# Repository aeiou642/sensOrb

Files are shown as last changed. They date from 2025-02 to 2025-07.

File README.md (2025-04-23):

PlatformIO Notes:
- Install PIO via. VSCode and follow standard installation instructions
- In the platformio.ini file, change the following;
- upload_port to whatever port the Serial to UART for the UPDI is connected to
- monitor_port to whatever port the Serial to UART the actual serial monitor is connected to

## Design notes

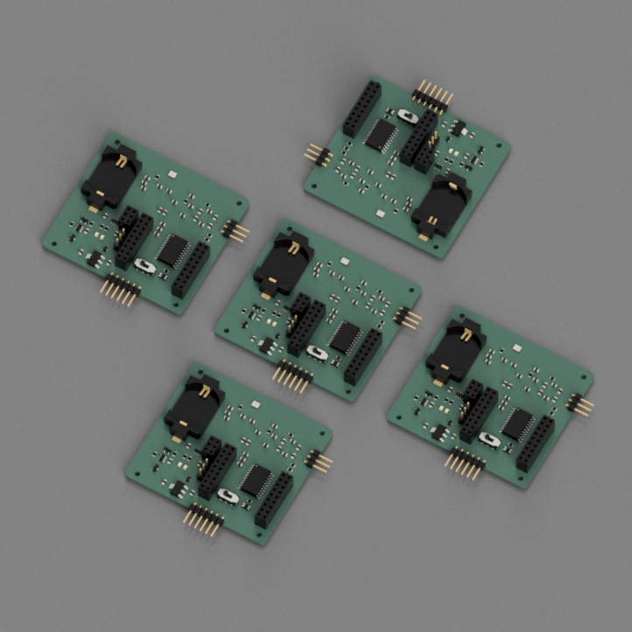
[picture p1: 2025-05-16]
Schematics & PCB/sensOrb/Node Layout v2.png

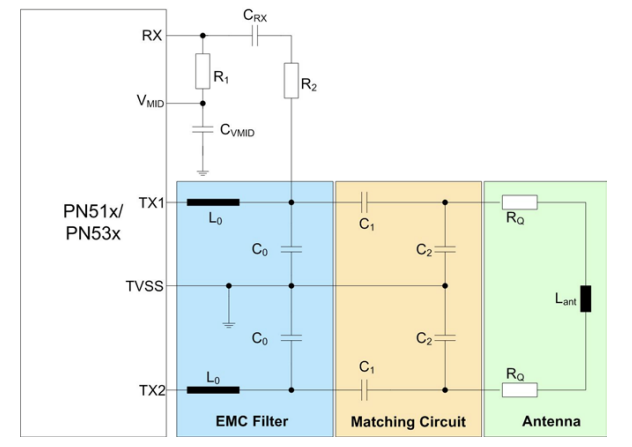
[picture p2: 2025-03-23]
Documentation/PN532/Antenna_RF_Design/AT1_Diagram.png

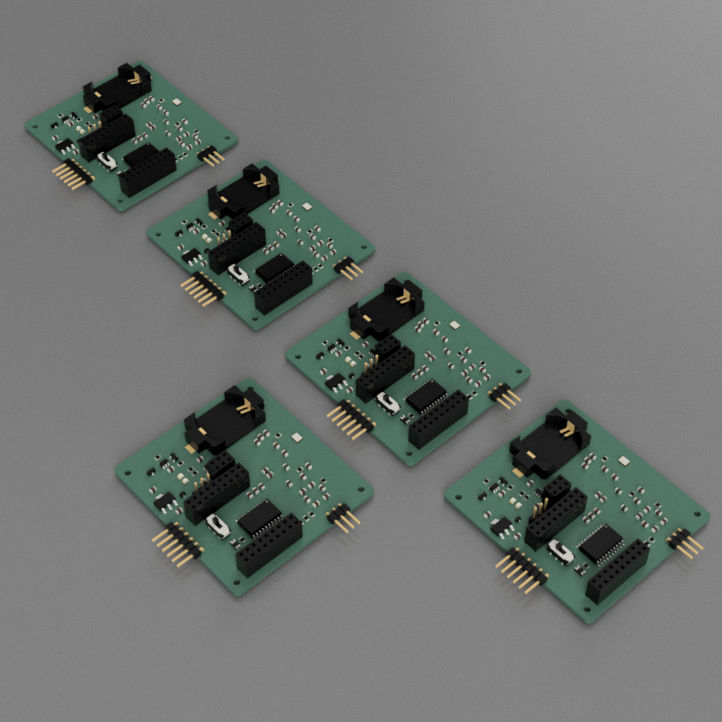
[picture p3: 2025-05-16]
Schematics & PCB/sensOrb/Node Layout v3.png

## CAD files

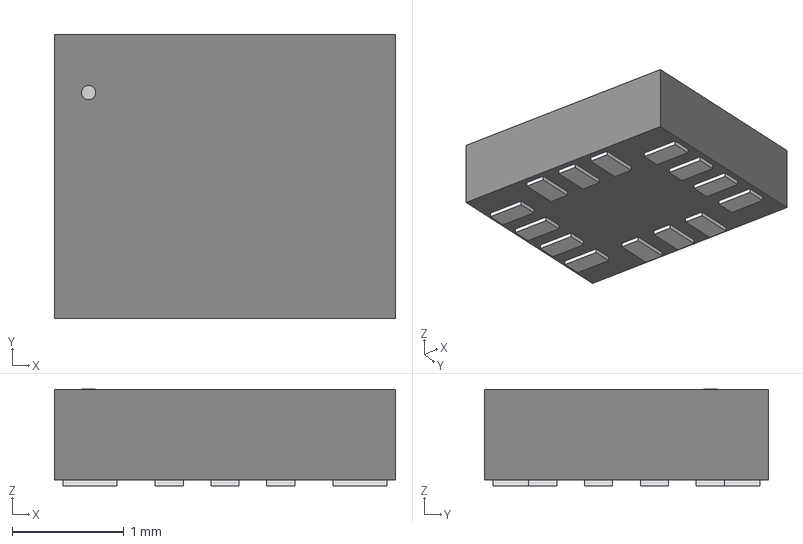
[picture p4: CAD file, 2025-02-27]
Documentation/BNO08x/BMI270_BOS.step
3.05 x 2.54 x 0.866 mm

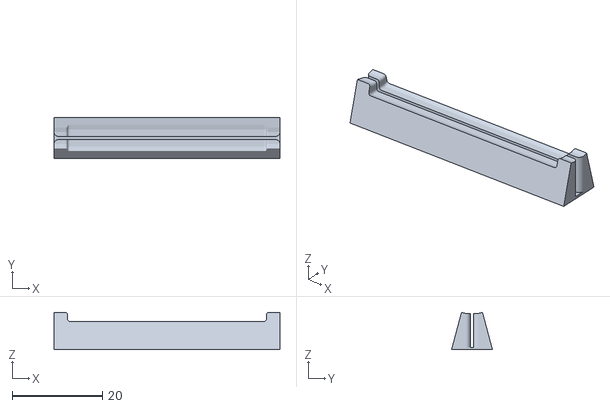
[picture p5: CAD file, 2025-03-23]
Documentation/PN532/PN532_Mount.stl
50.0 x 9.07 x 8.26

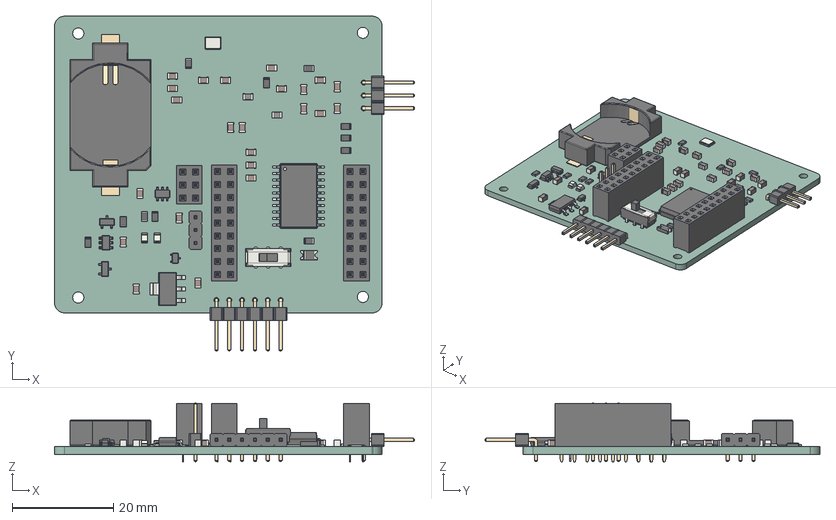
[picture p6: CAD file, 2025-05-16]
Schematics & PCB/sensOrb/salp_board.step
71.2 x 66.2 x 11.6 mm
R_0805_2012Metric x 11
SOT_223
L_0805_2012Metric x 2
C_0805_2012Metric x 23
PinSocket_2x03_P2.54mm_Vertical
PinHeader_1x06_P254mm_Horizontal
CuK_JS202011CQN_DPDT_straight
PinSocket_2x09_P2.54mm_Vertical x 2
LED_0805_2012Metric x 2
SOT_23_6
SOT_323_SC_70
PinHeader_1x03_P254mm_Horizontal
PinHeader_1x03_P254mm_Vertical
Keystone_1060_1x2032
SOT_23 x 2
TSOT_23_6
SOIC_20W_75x128mm_P127mm
D_1206
Crystal_SMD_SeikoEpson_TSX3225-4Pin_3.2x2.5mm_HandSoldering
_autosave-salp_board_PCB

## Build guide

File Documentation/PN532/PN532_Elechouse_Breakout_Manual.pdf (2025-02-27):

www.elechouse.com

# PN532 NFC RFID Module User Guide

Version V4

Introduction

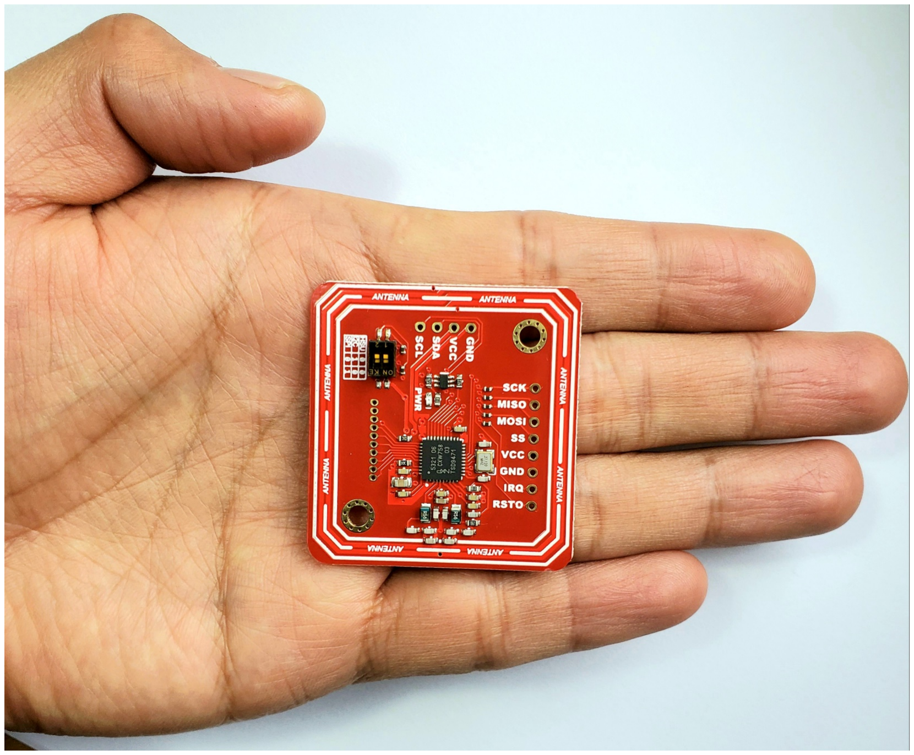
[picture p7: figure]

Near field communication (http://www.nfc-forum.org/aboutnfc) ( (http://www.nfc-forum.org/aboutnfc)NFC) (http://www.nfc-forum.org/aboutnfc) is (http://www.nfc-forum.org/aboutnfc) a set of standards for smartphones and similar devices to establish radio communication with each other by touching them together or bringing them into close proximity, usually no more than a few centimeters.

For electronics geeks, we also want to use NFC technology to make our own things. So we build this NFC RFID module. This module is built around NXP PN532. NXP PN532 is very popular in NFC area. And the company offers much technology documents to help developers. We developed this module based on the official documents. To make things easier, we also build library for this module.

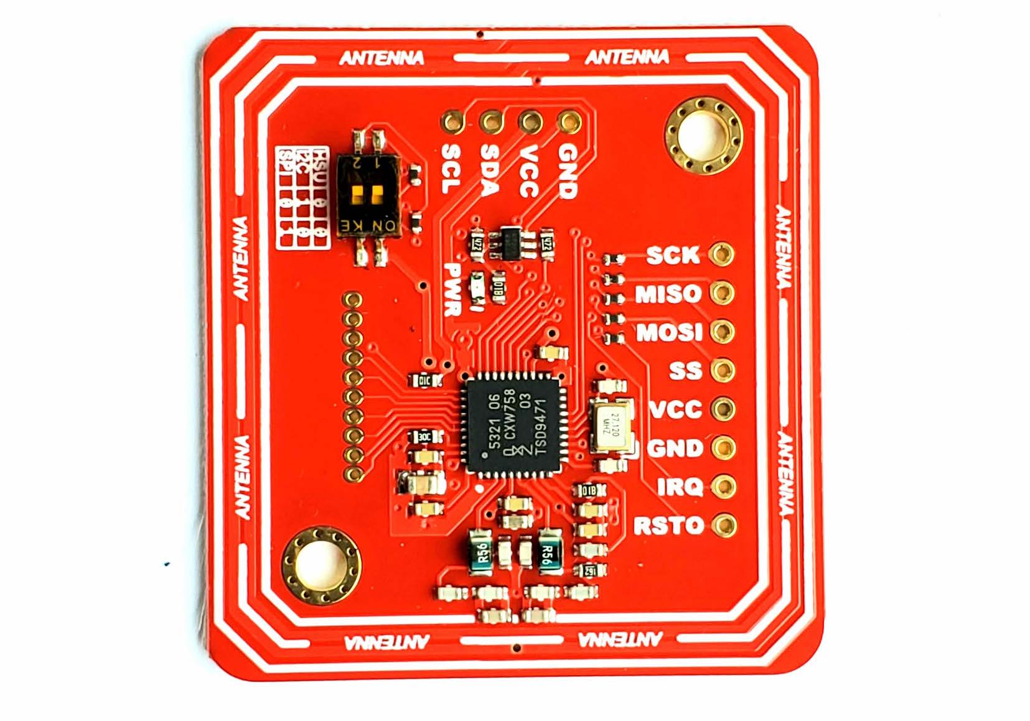
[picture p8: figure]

We have updated this module to version 4.

Compared with V3 have the following improvement:

Performance | PN532 NFC V3 | PN532 NFC V4 | Description
Reading Distance on PVC Mifare tag | 5~6cm | 6~8cm | Improved performance on IOS14443A tags
Reading Distance on PVC SRT512 | 1~2cm | 2~4cm | Improved performance on IOS14443B tags

Feature
1. Compatibility: it is compatible with V3 both in hardware and software.
2. Smaller: the size now is as small as 42.7mm*40.4mm*4mm
3. Easy to change mode: with a small SMD toggle Switch, it becomes very easy to change among IIC, SPI and HSU modes
4. Longer distance: the reading distance becomes 6~8cm

5. Open source Arduino library

Features
1. Support II2, SPI and HSU (High Speed UART)
2. RFID reader/writer mode support
- Mifare 1k, 4k, Ultralight, and DesFire cards
- ISO/IEC 14443-4 cards such as CD97BX, CD light, DesFire, P5CN072 (SMX)
- Innovision Jewel cards such as IRT5001 card
- FeliCa cards such as RCS_860 and RCS_854
3. Plug and play, Arduino compatible
4. Built in PCB Antenna, with 6cm~8cm communication distance
5. On-board level shifter, Standard 5V TTL for I2C and UART, 3.3V TTL SPI
6. Work as RFID reader/writer
7. Work as 1443-A card or a virtual card
8. Support NFC with Android phone
9. Small size: 43mm*41mm*4mm

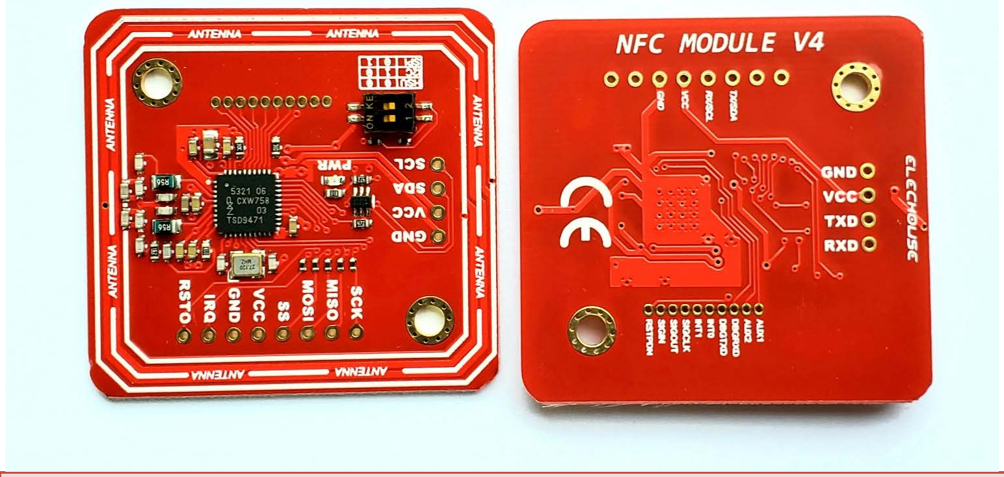
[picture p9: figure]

Interface

- VCC: 3.3V~5V
- Currency: Max 120mA

- I2C/UART: 3.3V~24V TTL
- SPI: 3.3V TTL with 100 ohm resistors in series. It could be connected directly to 5V interface of microcontroller such as Arduino.

The I2C and HSU shares the same pins. The definition of IIC pins is printed at front and the HSU’s is printed at the back. The HSU mode is configured as the default mode. But you could change the interface by setting the toggle switch.

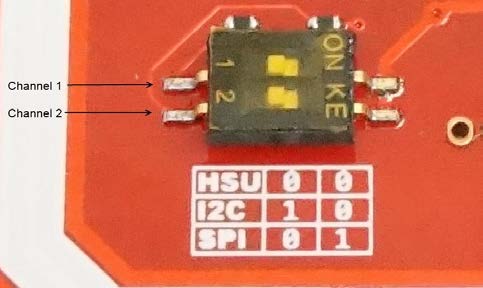
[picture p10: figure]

The switch setting is shown as follows: Working Interface Channel 1 Channel 2
HSU | OFF | OFF
I2C | ON | OFF
SPI | OFF | ON

We break all the PN532 pins out. The 1.27mm connector hole contains those pins which might not be used for most users. If some developers need to connect those pins, we could supply connectors.

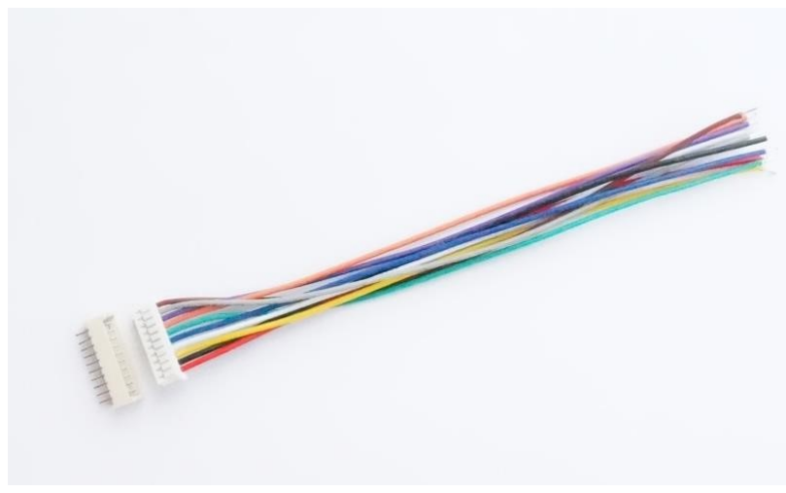
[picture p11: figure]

You could find this product here. (http://www.elechouse.com/elechouse/index.php?main_page=product_info&cPath=105_298&products_id=2244)

Hardware Installation

Solder the connector
The bended male pins come with the NFC board.

Some users might need soldering other types of connectors or directly solder wires on it. Anyway, make sure the wires go across the antenna lines in 90 degree.

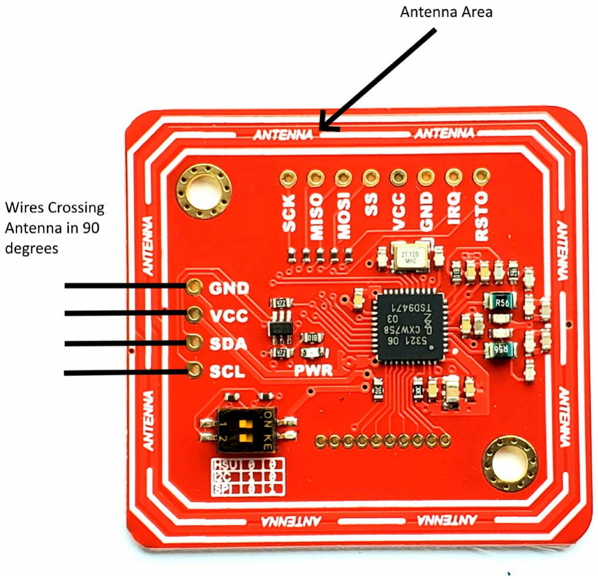
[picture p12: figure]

Connect with Arduino
If without the sensor shield, please connect as following:
Mode | PN532 Module | Arduino UNO | Arduino Leonardo | Arduino Mega (2560) | Arduino Due
Power | VCC | 5V | 5V | 5V | 5V
| GND | GND | GND | GND | GND
IIC/I2C Mode | SDA | A4/SDA | Pin 2 /SDA | Pin 20 /SDA | Pin 20 /SDA
| SCL | A5/SCL | Pin 3/SCL | Pin 21/SCL | Pin 21/SCL
HSU Mode | TXD | Pin 0 | Could not
present
message in
Serial
Monitor on
PC
| | | Pin 0 | Pin 19 | Pin 19
| RXD | Pin 1 | Pin 1 | Pin 18 | Pin 18
SPI Mode | SCK | Pin 13 or ICSP-3 | ICSP-3 | Pin 52 or ICSP-3 | ICSP-3 | Note: SPI on Due is still in developing
MISO | Pin 12 or ICSP-1 | ICSP-1 | Pin 50 or ICSP-1 | ICSP-1
MOSI | Pin 11 or ICSP-4 | ICSP-4 | Pin 51 or ICSP-4 | ICSP-4
SS | Pin 10 | Pin 10 | Pin 10 | Pin 10
Arduino UNO only has one serial interface which is also connected to USB port to PC. In HSU mode, the serial monitor could not be used as message displaying windows.

Function Test

RFID Reader/Writer
Here we show how to read and write RFID card with this module.

Download the library (https://github.com/elechouse/PN532) PN532 (https://github.com/elechouse/PN532) at (https://github.com/elechouse/PN532) our github page. You could find 4 folders in the library. Unzip the 4 folders at the library folder in Arduino IDE.

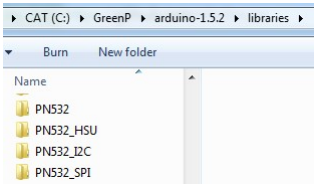
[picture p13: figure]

Start Arduino IDE and choose the example:

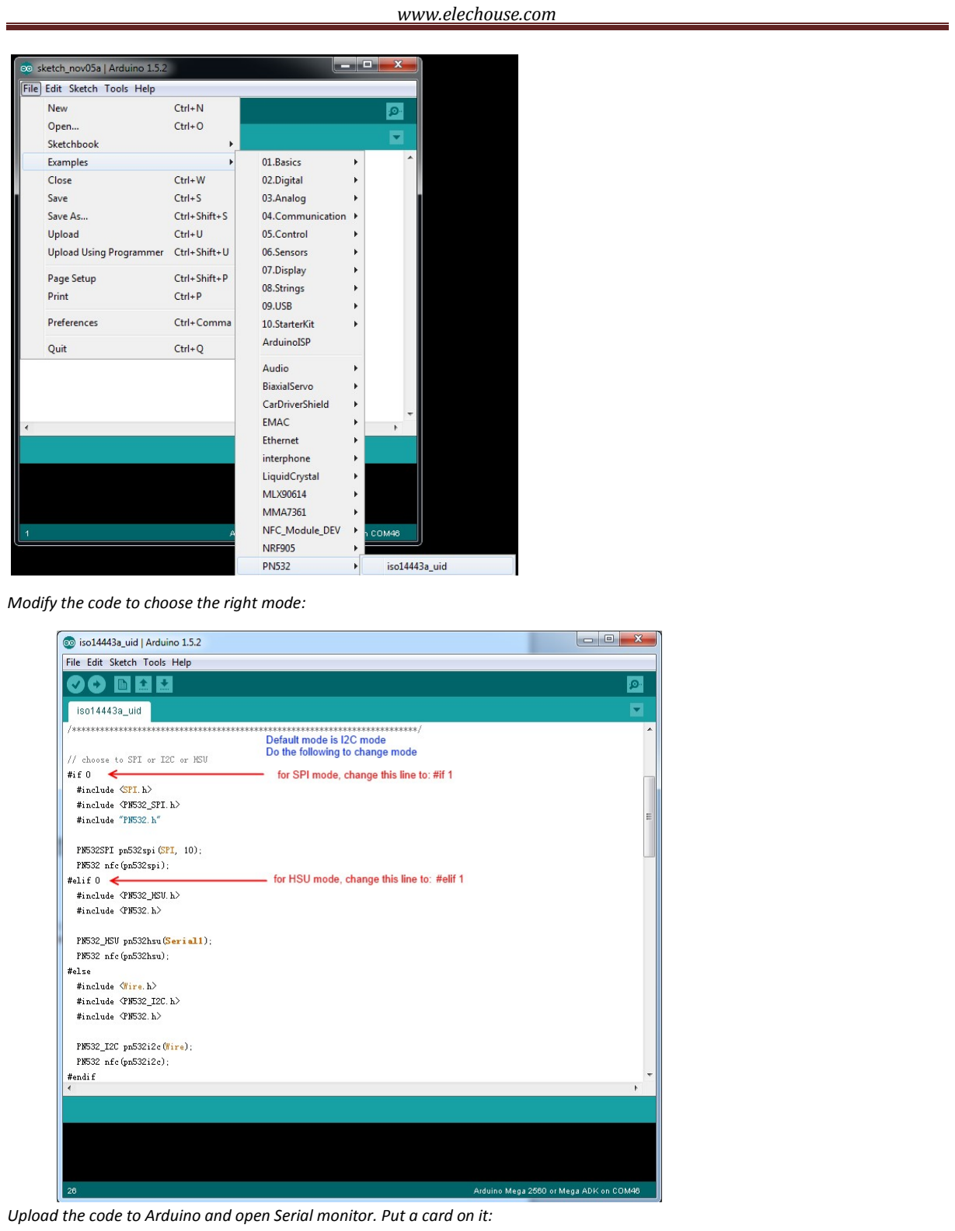
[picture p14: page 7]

Modify the code to choose the right mode:

Upload the code to Arduino and open Serial monitor. Put a card on it:

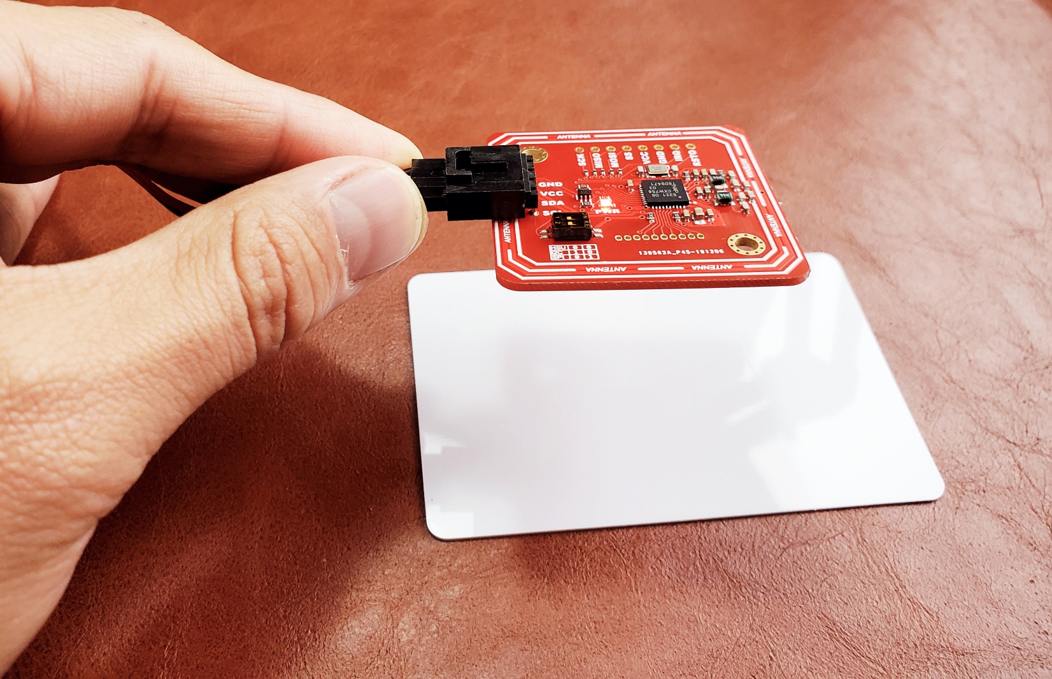
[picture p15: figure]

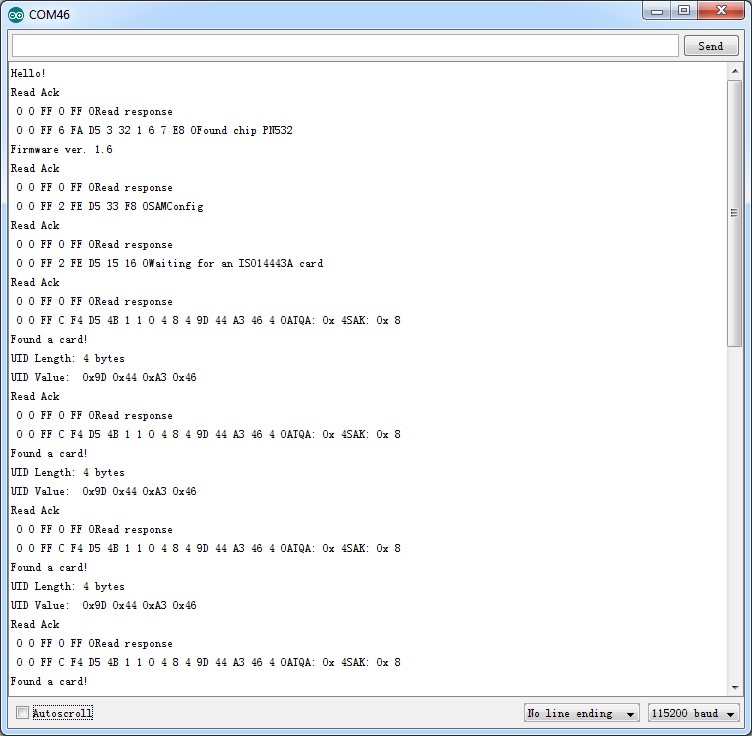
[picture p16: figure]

You could also try other reading/writing example code in the library.

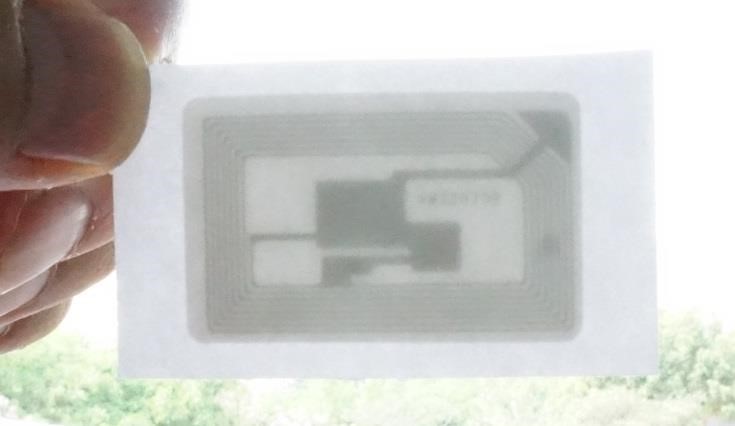
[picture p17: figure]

It also supports reading flexible tag. We tested flexible tags of Mifare 1 S50 and Ultralight. The reading distance is up to 5cm.

You could find those flexible tags here. (http://www.elechouse.com/elechouse/index.php?main_page=product_info&cPath=90_93&products_id=2243)

P2P NFC
Currently we are still developing the software. The P2P NFC communication between two PN532 modules is only supported by I2C mode. Please download this library. (http://www.elechouse.com/elechouse/images/product/PN532%20NFC%20Module/PN532_NFC_elechouse.rar)
Note, while testing this library, please remove the libraries in the testing above (or other PN532 libraries) to other folders. Otherwise they might conflict.

Here we need two Arduino boards to test this function. Basically we will program one NFC module as Initiator, and the other as Target.

Please upload the following two examples to the two Arduino board:

- NFC_p2p_initiator
- NFC_p2p_target

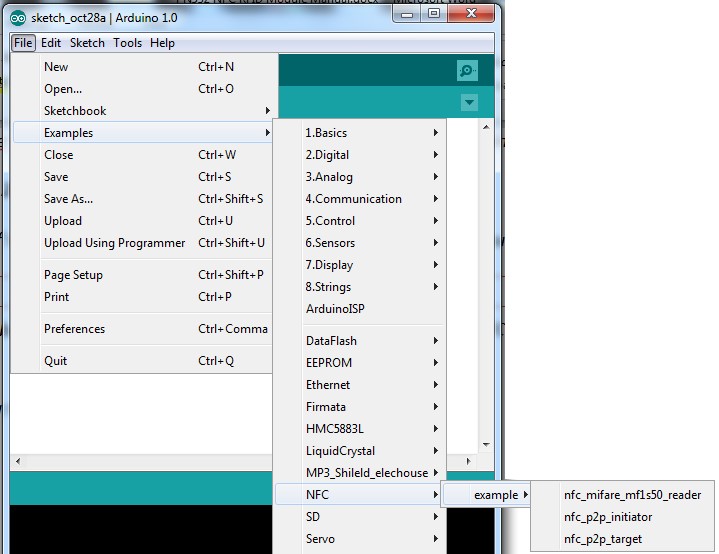
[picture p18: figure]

After uploading the sketches, open the Serial Monitor. Please note that Arduino IDE doesn’t support opening 2 Serial Monitors. So you need another Serial Tool. Here we have 2 versions of Arduino IDE installed in my PC: Arduino 0022 and Arduino 1.0. We open the two and could have two Serial Monitor working. Note the baud rate is 115200.

Target:

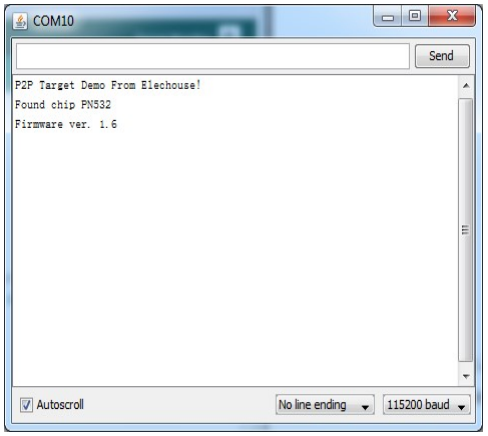
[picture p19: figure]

Initiator:

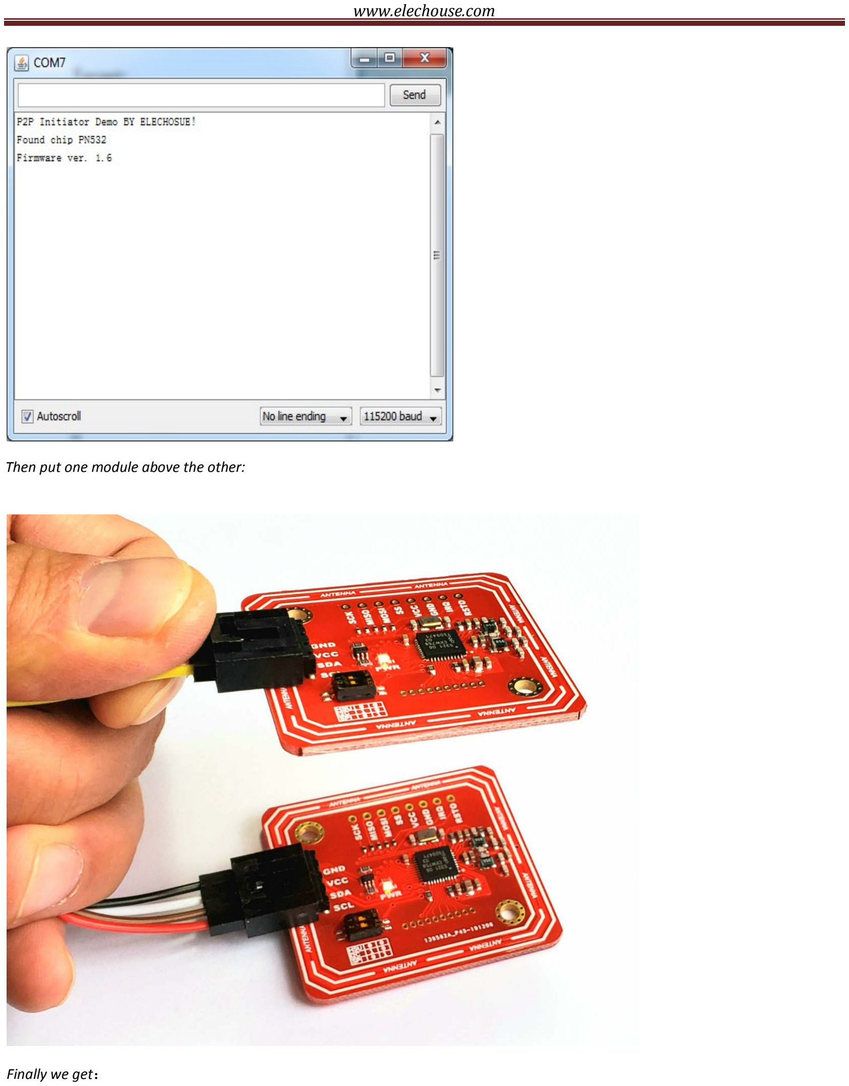
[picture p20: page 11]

Then put one module above the other:

Finally we get：

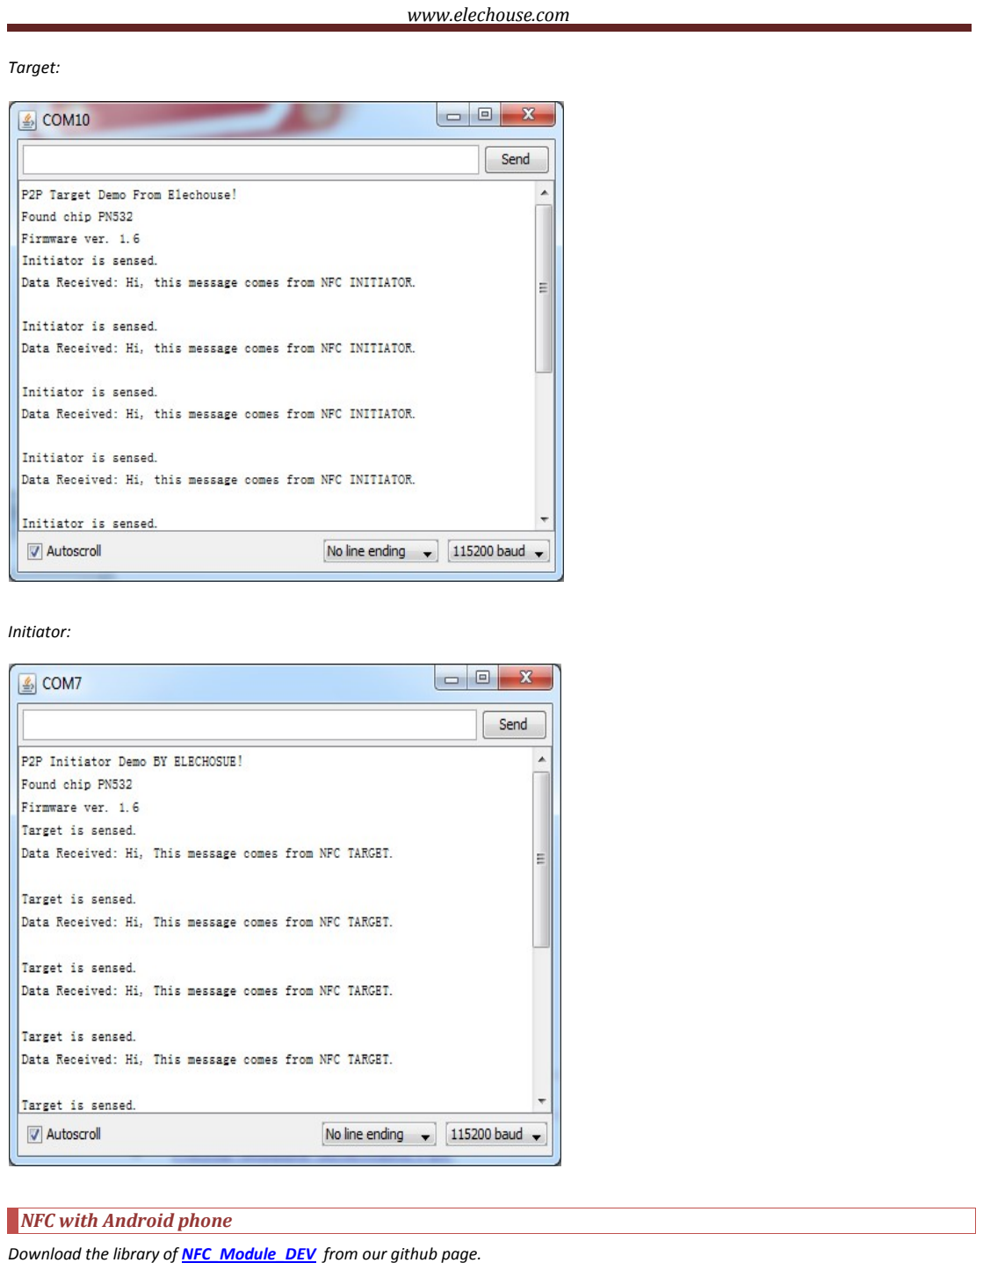
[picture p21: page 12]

Target:

Initiator:

NFC with Android phone
Download the library of (https://github.com/elechouse/NFC_Module_DEV) NFC_Module_DEV (https://github.com/elechouse/NFC_Module_DEV) from our github page.

Note, while testing this library, please remove the libraries in the testing above (or other PN532 libraries) to other folders. Otherwise they might conflict.

Currently this library only supports HSU mode. We are still working on more modes. If you want to use SPI mode, you could try (https://github.com/Seeed-Shield/NFC_Shield_DEV) NFC_Shield_DEV. (https://github.com/Seeed-Shield/NFC_Shield_DEV) Just connect Arduino with our PN532 module through SPI interface in the way shown in the table above.

Open the example in Arduino Due:

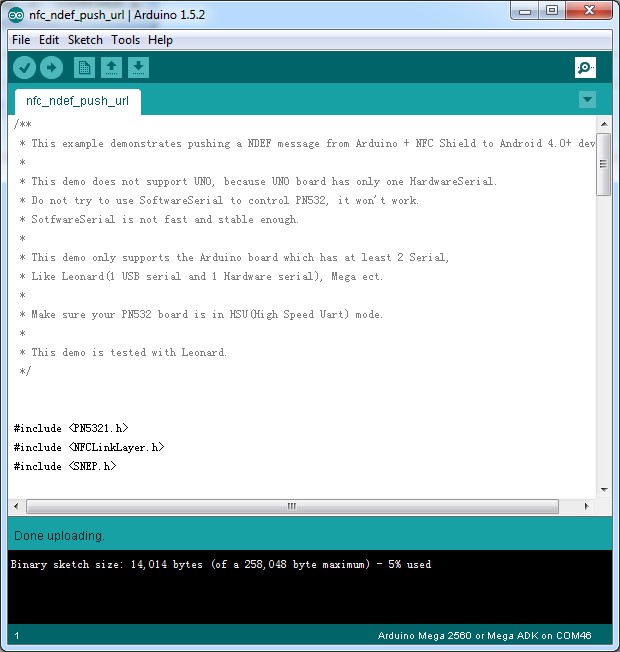
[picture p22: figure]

Upload the code to Arduino, and open Serial Monitor:

Put an NFC-support phone on the module:

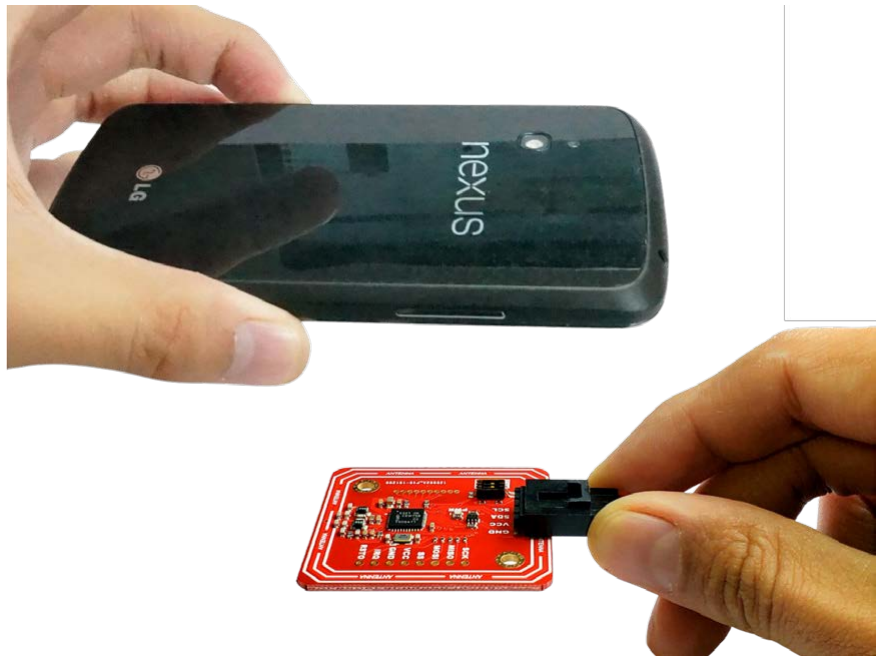
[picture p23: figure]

On Android phone, if you have set the default browser, it will start the browser and visit our website: www.elechouse.com

If it doesn’t start the browser, please open the browser and try again. Here we tested HTC one and Google Nexus 4. They all work very well. Different NFC phones might have different NFC ICs. If your phone doesn’t work with it, try to google information to check if your phone NFC chip is compatible with PN532.

On Serial Monitor you could get the following result:

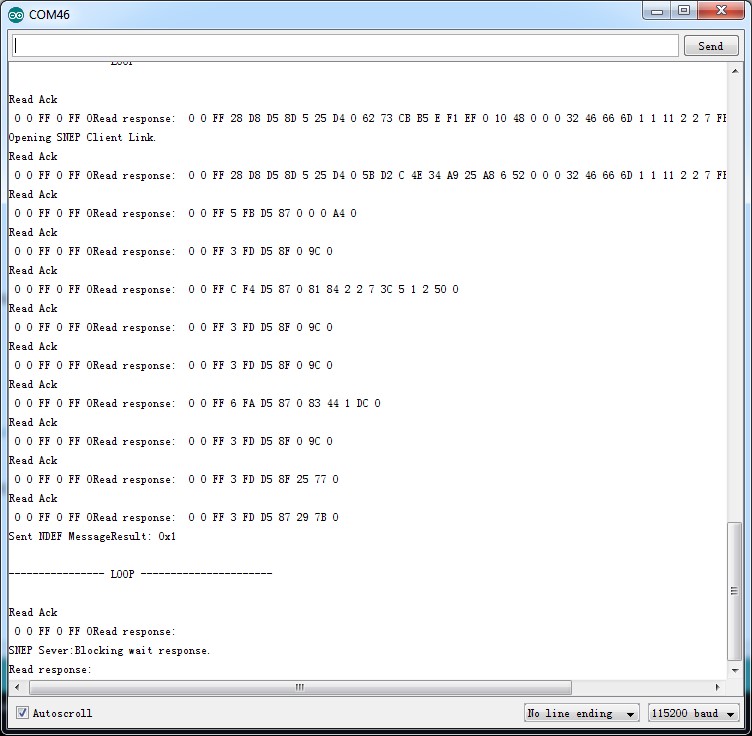
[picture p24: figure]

Useful link
PN532 Module Schematic PDF (http://www.elechouse.com/elechouse/images/product/PN532_module_V3/PN532_shematic_drowing.pdf)
NXP PN532 User Manual (http://www.nxp.com/documents/user_manual/141520.pdf)
DWG DIMENSION FILE (http://www.elechouse.com/elechouse/images/product/NFCV4/NFC_V4_dimension.DWG)
Library: (https://github.com/elechouse/PN532) PN532 (https://github.com/elechouse/PN532) or (https://github.com/elechouse/NFC_Module_DEV) NFC_Module_DEV (https://github.com/elechouse/NFC_Module_DEV)

Where to buy
Please visit this page to buy this product: (http://www.elechouse.com/elechouse/index.php?main_page=product_info&cPath=90_93&products_id=2242) PN532 NFC module (http://www.elechouse.com/elechouse/index.php?main_page=product_info&cPath=90_93&products_id=2242)

Disclaimer and Revisions
[FCC Declare]

The information in this document may change without notice. If you have any problem about it, please visit www.elechouse.com to contact us.

Revision History
Rev. | Date | Author | Description

A | Oct. 25th , 2012 | Wilson | Initial version
B | Nov. 5th, 2013 | Wilson | Modify information for V3

FCC WARNING
FCC Caution: Any changes or modifications not expressly
approved by the party responsible for compliance could void the user's authority to operate this equipment.
This device complies with Part 15 of the FCC Rules.
Operation is subject to the following two conditions: (1) This device may not cause harmful interference, and (2) this device must accept any interference received, including interference that may cause undesired operation.
This device and its antenna(s) must not be co-located or operating in conjunction with any other antenna or transmitter.
15.105 Information to the user.
(b) For a Class B digital device or peripheral, the instructions furnished the
user shall include the following or similar statement, placed in a prominent location in the text of the manual:
Note: This equipment has been tested and found to comply
with the limits for a Class B digital device, pursuant to part 15 of the FCC Rules. These limits are designed to provide reasonable protection against harmful interference in a residential installation. This equipment generates, uses and can radiate radio frequency energy and, if not installed and used in
accordance with the instructions, may cause harmful interference to radio communications. However, there is no guarantee that interference will not occur in a particular installation. If this equipment does cause harmful interference to radio or television reception, which can be determined by turning the equipment off and on, the user is encouraged to try to correct the interference by one or more of the following measures:
—Reorient or relocate the receiving antenna.
—Increase the separation between the equipment and receiver.
—Connect the equipment into an outlet on a circuit different from that to which
the receiver is connected.
—Consult the dealer or an experienced radio/TV technician for help.
This equipment complies with FCC radiation exposure limits set forth for an uncontrolled environment. This equipment should be installed and operated with minimum distance 20 cm between the radiator and your body.
Radiation Exposure Statement:
This equipment complies with FCC radiation exposure limits set forth for an uncontrolled environment.
This transmitter must not be co-located or operating in conjunction with any other antenna or transmitter.
The availability of some specific channels and/or operational frequency bands are country dependent and are firmware programmed at the factory to match the intended destination.
The firmware setting is not accessible by the end user.
The final end product must be labelled in a visible area with the following: “Contains Transmitter Module 2ABVM-ELECHNFCV4”

## Requirement per KDB996369 D03

### 2.2 List of applicable FCC rules

List the FCC rules that are applicable to the modular transmitter. These are the rules that specifically establish the bands of operation, the power, spurious emissions, and operating fundamental frequencies. DO NOT list compliance to unintentional-radiator rules (Part 15 Subpart
B) since that is not a condition of a module grant that is extended to a host manufacturer. See also Section 2.10 below concerning the need to notify host manufacturers that further testing is required.3
Explanation: This module meets the requirements of FCC part 15C (15.225).it specifically establish the Radiated Spurious Emission, Frequency Tolerance, Occupied Bandwidth

### 2.3 Summarize the specific operational use conditions

Describe use conditions that are applicable to the modular transmitter, including for example any limits on antennas, etc. For example, if point-to-point antennas are used that require reduction in power or compensation for cable loss, then this information must be in the instructions. If the use condition limitations extend to professional users, then instructions must state that this information also extends to the host manufacturer’s instruction manual. In addition, certain information may also be needed, such as peak gain per frequency band and minimum gain, specifically for master devices in 5 GHz DFS bands.
Explanation: The EUT has an pcb antenna, the antenna can be replaced by other authorized antennas, and the gain of each replacement antenna is no more than 5dBi

### 2.4 Limited module procedures

If a modular transmitter is approved as a “limited module,” then the module manufacturer isresponsible for approving the host environment that the limited module is used with. The manufacturer of a limited module must describe, both in the filing and in the installation instructions, the alternative means that the limited module manufacturer uses to verify that the host meets the necessary requirements to satisfy the module limiting conditions.
A limited module manufacturer has the flexibility to define its alternative method to address the conditions that limit the initial approval, such as: shielding, minimum signaling amplitude, buffered modulation/data inputs, or power supply regulation. The alternative method could include that the limited module manufacturer reviews detailed test data or host designs prior to giving the host manufacturer approval.

This limited module procedure is also applicable for RF exposure evaluation when it is necessary to demonstrate compliance in a specific host. The module manufacturer must state how control of the product into which the modular transmitter will be installed will be maintained such that full compliance of the product is always ensured. For additional hosts other than the specific host originally granted with a limited

module, a Class II permissive change is required on the module grant to register the additional host as a specific host also approved with the module.
Explanation: The module is a limit module.

### 2.6 RF exposure considerations

It is essential for module grantees to clearly and explicitly state the RF exposure conditions that permit a host product manufacturer to use the module. Two types of instructions are required for RF exposure information: (1) to the host product manufacturer, to define the application conditions (mobile, portable – xx cm from a person’s body); and (2) additional text needed for the host product manufacturer to provide to end users in their end-product manuals. If RF exposure statements and use conditions are not provided, then the host product manufacturer is required to take responsibility of the module through a change in FCC ID (new application).

Explanation: This module complies with FCC RF radiation exposure limits set forth for an uncontrolled environment, This equipment should be installed and operated with a minimum distance of 20 centimeters between the radiator and your body." This module is designed to comply with the FCC statement, FCC ID is: 2ABVM-ELECHNFCV4.

### 2.7 Antennas

A list of antennas included in the application for certification must be provided in the instructions. For modular transmitters approved as limited modules, all applicable professional installer instructions must be included as part of the information to the host product manufacturer. The antenna list shall also identify the antenna types (monopole, PIFA, dipole, etc. (note that for example an “omni-directional antenna” is not considered to be a specific “antenna type”)).
For situations where the host product manufacturer is responsible for an external connector, for example with an RF pin and antenna trace design, the integration instructions shall inform the installer that unique antenna connector must be used on the Part 15 authorized transmitters used in the host product. The module manufacturers shall provide a list of acceptable unique connectors.
Explanation: The EUT has an pcb antenna, the antenna can be replaced by other authorized antennas, and the gain of each replacement antenna is no more than 5dBi

### 2.8 Label and compliance information

Grantees are responsible for the continued compliance of their modules to the FCC rules. This includes advising host product manufacturers that they need to provide a physical or e-label stating “Contains FCC ID” with their finished product. See Guidelines for Labeling and User Information for RF Devices – KDB Publication 784748.

Explanation: The host system using this module, should have label in a visible area indicated the following texts: "Contains FCC ID: 2ABVM-ELECHNFCV4.

### 2.9 Information on test modes and additional testing requirements5

Additional guidance for testing host products is given in KDB Publication 996369 D04 Module Integration Guide. Test modes should take into consideration different operational conditions for a stand-alone modular transmitter in a host, as well as for multiple simultaneously transmitting modules or other transmitters in a host product.
The grantee should provide information on how to configure test modes for host product evaluation for different operational conditions for a stand-alone modular transmitter in a host, versus with multiple, simultaneously transmitting modules or other transmitters in a host.
Grantees can increase the utility of their modular transmitters by providing special means, modes, or instructions that simulates or characterizes a connection by enabling a transmitter. This can greatly simplify a host manufacturer’s determination that a module as installed in a host complies with FCC requirements.
Explanation: HK ELECHOUSE ELECTRONICS TECHNOLOGY CO.,LIMITED can increase the utility of our modular transmitters by providing instructions that simulates or characterizes a connection by enabling a transmitter.

### 2.10 Additional testing, Part 15 Subpart B disclaimer

The grantee should include a statement that the modular transmitter is only FCC authorized for the specific rule parts (i.e., FCC transmitter rules) listed on the grant, and that the host product manufacturer is responsible for compliance to any other FCC rules that apply to the host not covered by the modular transmitter grant of certification. If the grantee markets their product as being Part 15
Subpart B compliant (when it also contains unintentional-radiator digital circuity), then the grantee shall provide a notice stating that the final host product still requires Part 15 Subpart B compliance testing with the modular transmitter installed.
Explanation: The module without unintentional-radiator digital circuity, so the module does not require an evaluation by FCC Part 15 Subpart B. The host shoule be evaluated by the FCC Subpart B.

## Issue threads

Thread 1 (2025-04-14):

I2C Peer-to-Peer

aeiou642, 2025-04-14:
this probably wont work, but I could probably write some driver code with enough fanangaling, although it realistically doesn't make sense to do it this way, since;
- each board should only have one PN532 on it anyways
- I2C is relatively slow at a max transfer speed of 400 khz (which also causes some instability)

aeiou642, 2025-04-21:
not worth it;
- basic libraries don't support it, and I can't justify the extra 3~ weeks it would take to fully implement this properly. tgInitAsTarget is realistically the only reason why I would even consider this setup.
- I2C is slower compared to SPI; SPI is slower than HSU, but simpler than HSU; HSU would require additional libraries to simulate an additional UART line (from what I understand; see XHL's PN532 lib)
- as previously mentioned, each board would only have one PN532 on it; for a simple example, i don't really care about being able to support multiple, since these modules have an area smaller than 3~ cm, the antennas would have to be fully extended out to make use of extra modules anyways. maybe for later

Closed 2025-04-21.

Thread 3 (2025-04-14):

Board Layout

aeiou642, 2025-04-14:
board layout needs to be updated with the new antenna design, and needs to be swapped out for SPI stuff

aeiou642, 2025-04-15:
PA_ - CS
PA3 - SCK
PA2 - MISO
PA1 - MOSI

Don't forget to hit the DIP switches either on the breakout boards! (invert I2C selection)

Using the alternative pins doesn't work with the current implementation

aeiou642, 2025-04-21:
TODO: add things for IRQ (set a GPIO pin to it on the ATTiny3226)

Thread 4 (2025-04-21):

Serial/UPDI

aeiou642, 2025-04-21:
because of tarriffs, basic DPDT switches are exponentially more expensive than usual; the simplest solution is [this 2 DPDT DIP switch](https://app-grayhill-website-cms-prod-001.azurewebsites.net/media/ob5jm120/76-78-dpdt-datasheet.pdf) but there's surely an easier way to do it. this is for the Serial/UPDI header

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

TODO:
- find a better DPDT
- find the proper zener diode (JC has this I believe) or find a proper value for the Schottky diode i've got going on

aeiou642, 2025-04-23:
done, cheaper alternative found
footprint: Button_Switch_THT:SW_CK_JS202011CQN_DPDT_Straight
D1 / 470 swapped for a BZS55C5V1 (basically a zener diode)

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

Closed 2025-04-23.

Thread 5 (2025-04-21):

Li-Po/battery solutions

aeiou642, 2025-04-21:
TODO:
- find charging circuit; probably a TP4054, and import footprints/other stuff into KiCAD:
https://www.digikey.com/en/products/detail/umw/TP4054/17635214

- find a new over/undercurrent board; potentially keep the old one too
- keep the other stuff saved in another repo for now

aeiou642, 2025-04-23:
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

Done; needs verification for the BAT54CW; it should work, but the forward voltage drop might be too much. Not sure

aeiou642, 2025-05-03:
done for now - should work just fine; the BAT54CW can always be replaced by a jumper if needed

Closed 2025-05-03.

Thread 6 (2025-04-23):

PN532 overhaul

aeiou642, 2025-04-23:
- [x] add 100 ohm resistor and discrete header 1 for
  - [ ]  - SCK
  - [ ]   - MISO
  - [ ]   - MOSI/SDA/TX
  - [ ]   - SSEL/SCL/RX
  - [ ]   - IRQ
- [ ] add discrete header 2 for
  - [ ]   - RSTPD_N
  - [ ]   - SIGIN
  - [ ]   - SIGOUT
  - [ ]   - SIGCLK
  - [ ]   - INT1
  - [ ]   - INT0
  - [ ]   - DBG_TX
  - [ ]   - DBG_RX
  - [ ]   - AUX2
  - [ ]   - AUX1
- [ ] add discrete header 3 for
  - [ ] SCL
  - [ ] SDA
  - [ ] VCC / 5V
  - [ ] GND
- [ ] OCD (using a 2N7002DM or equivalent)
  - [ ] - VCC / 3.3V pullup for SSEL/SCL/RX (4.7k) to SCL
  - [ ]   - VCC / 3.3V pullup for MOSI/SDA/TX (4.7k) to SDA
- [x] AVDD pulled high to 3.3V w/ decoup 0.1 uF to gnd
- [ ] TVDD, TVSS2, TVSS1, DVSS, COPPER (41) to gnd

aeiou642, 2025-04-23:
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

pulldown resistors for I0 and I1

aeiou642, 2025-04-23:
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
AVDD pulled high to 3.3V w/ decoup 0.1 uF to gnd
**Additionally, VCC was (properly) added to each line** See s7.2 PN532_C1

aeiou642, 2025-05-03:
added jumper pads instead of headers to save space and reserve for testing - done for now

Closed 2025-05-03.

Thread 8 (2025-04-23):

tgInitAsTarget not functioning

aeiou642, 2025-04-23:
tgInitAsTarget wont work; there isn't a top-level/hardware reason why it shouldn't be working; technically it says it only works with I2C, but that doesn't matter, since the same commands are sent either way. to start:

- check buffer
- check ACK/NACK bits
- remove wrappers
- verify tag initialization

in the worst case scenario, rewrite some of the code and place changes here

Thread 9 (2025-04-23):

ERC Validation

aeiou642, 2025-04-23:
Perform and do ERC Validations. Ignore some errors that are generated for the PN532 (as schematics show they are connected to GND but the ERC complains about it)

aeiou642, 2025-04-27:
- Removed GND from VOR line
- Got rid of the DPDT for the SPI/I2C selection; unfortunately, as it stands, I'm just trying to get it working with SPI first.

aeiou642, 2025-04-27:
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

DVSS, TVSS1, TVSS2, and AVSS should be connected to ground. Both the Adafruit PN532 and Seeed Studio module support this, along with the datasheet.

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

aeiou642, 2025-05-03:
done - all other errors can be ignored for now - not enough time to add power flags to each line

Closed 2025-05-03.

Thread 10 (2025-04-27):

Modify Crystal Layout

aeiou642, 2025-04-27:
I'm pretty sure the wrong foodprint was selected
TODO:
- Find the proper footprint for the select crystal OR swap it out for another one

aeiou642, 2025-04-27:
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
TODO: Verify schematic

aeiou642, 2025-05-03:
fixed crystal layout

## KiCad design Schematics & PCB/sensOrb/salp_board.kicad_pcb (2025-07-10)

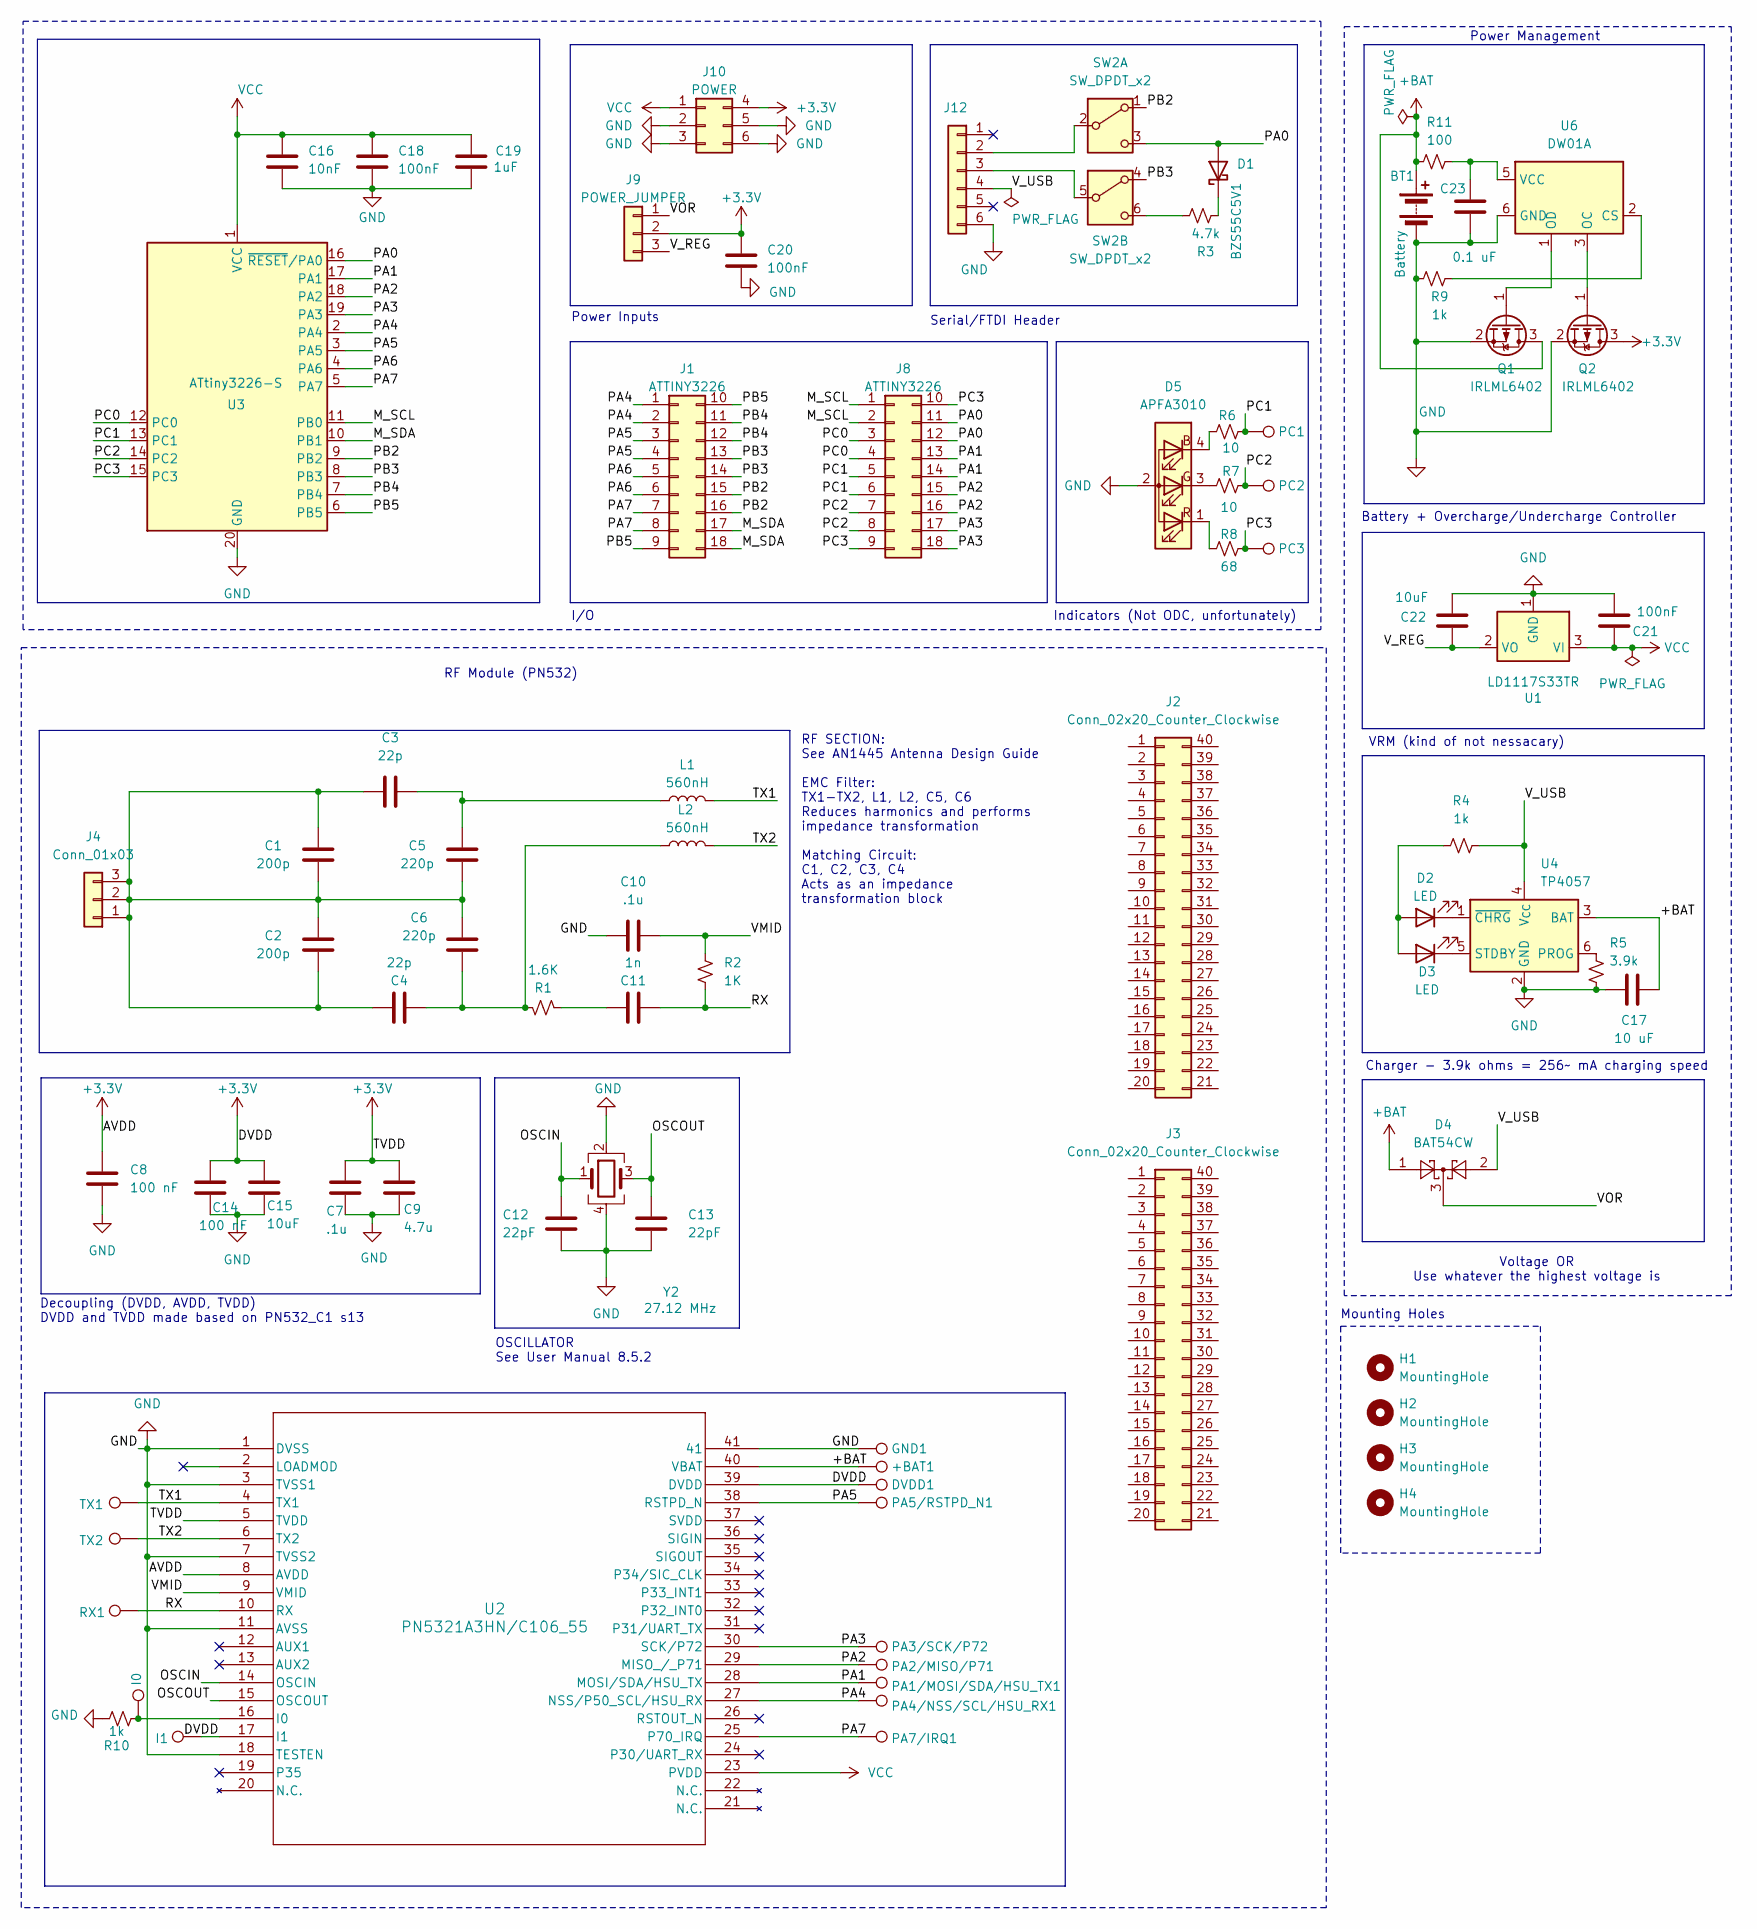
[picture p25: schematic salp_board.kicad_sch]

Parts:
+BAT1: TestPoint; TestPoint_Pad_D1.0mm
BT1: Battery; BatteryHolder_Keystone_1060_1x2032
C1, C2: 200p; C_0805_2012Metric_Pad1.18x1.45mm_HandSolder
C3, C4: 22p; C_0805_2012Metric_Pad1.18x1.45mm_HandSolder
C5, C6: 220p; C_0805_2012Metric_Pad1.18x1.45mm_HandSolder
C7, C10: .1u; C_0805_2012Metric_Pad1.18x1.45mm_HandSolder
C8, C14: 100 nF; C_0805_2012Metric_Pad1.18x1.45mm_HandSolder
C9: 4.7u; C_0805_2012Metric_Pad1.18x1.45mm_HandSolder
C11: 1n; C_0805_2012Metric_Pad1.18x1.45mm_HandSolder
C12, C13: 22pF; C_0805_2012Metric_Pad1.18x1.45mm_HandSolder
C15, C22: 10uF; C_0805_2012Metric_Pad1.18x1.45mm_HandSolder
C16: 10nF; C_0805_2012Metric_Pad1.18x1.45mm_HandSolder
C17: 10 uF; C_0805_2012Metric_Pad1.18x1.45mm_HandSolder
C18, C20, C21: 100nF; C_0805_2012Metric_Pad1.18x1.45mm_HandSolder
C19: 1uF; C_0805_2012Metric_Pad1.18x1.45mm_HandSolder
C23: 0.1 uF; C_0805_2012Metric_Pad1.18x1.45mm_HandSolder
D1: BZS55C5V1; D_1206_3216Metric_Pad1.42x1.75mm_HandSolder
D2, D3: LED; LED_0805_2012Metric
D4: BAT54CW; SOT-323_SC-70
D5: APFA3010; LED_Kingbright_APFA3010_3x1.5mm_Horizontal
DVDD1: TestPoint; TestPoint_Pad_D1.0mm
GND1: TestPoint; TestPoint_Pad_D1.0mm
H1, H2, H3, H4: MountingHole; MountingHole_2.2mm_M2
I0, I1: TestPoint; TestPoint_Pad_D1.0mm
J1, J8: ATTINY3226; PinSocket_2x09_P2.54mm_Vertical
J2, J3: Conn_02x20_Counter_Clockwise
J4: Conn_01x03; PinHeader_1x03_P2.54mm_Horizontal
J9: POWER_JUMPER; PinHeader_1x03_P2.54mm_Vertical
J10: POWER; PinSocket_2x03_P2.54mm_Vertical
J12: PinHeader_1x06_P2.54mm_Horizontal
L1, L2: 560nH; L_0805_2012Metric_Pad1.15x1.40mm_HandSolder
PA1/MOSI/SDA/HSU_TX1, PA2/MISO/P71, PA3/SCK/P72, PA4/NSS/SCL/HSU_RX1, PA5/RSTPD_N1, PA7/IRQ1: TestPoint; TestPoint_Pad_D1.0mm
PC1, PC2, PC3: TestPoint; TestPoint_Pad_D1.0mm
Q1, Q2: IRLML6402; SOT-23
R1: 1.6K; R_0805_2012Metric_Pad1.20x1.40mm_HandSolder
R2: 1K; R_0805_2012Metric_Pad1.20x1.40mm_HandSolder
R3: 4.7k; R_0805_2012Metric_Pad1.20x1.40mm_HandSolder
R4, R9, R10: 1k; R_0805_2012Metric_Pad1.20x1.40mm_HandSolder
R5: 3.9k; R_0805_2012Metric_Pad1.20x1.40mm_HandSolder
R6, R7: 10; R_0805_2012Metric_Pad1.20x1.40mm_HandSolder
R8: 68; R_0805_2012Metric_Pad1.20x1.40mm_HandSolder
R11: 100; R_0805_2012Metric_Pad1.20x1.40mm_HandSolder
RX1: TestPoint; TestPoint_Pad_D1.0mm
SW2: SW_DPDT_x2; SW_CK_JS202011CQN_DPDT_Straight
TX1, TX2: TestPoint; TestPoint_Pad_D1.0mm
U1: LD1117S33TR; SOT-223-3_TabPin2
U2: PN5321A3HN/C106_55; QFN40G-0.5-6X6MM
U3: ATtiny3226-S; SOIC-20W_7.5x12.8mm_P1.27mm
U4: TP4057; TSOT-23-6
U6: DW01A; SOT-23-6
Y2: 27.12 MHz; Crystal_SMD_SeikoEpson_TSX3225-4Pin_3.2x2.5mm_HandSoldering

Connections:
+3.3V: C7.1, C8.1, C9.1, C14.1, C15.1, C20.1, DVDD1.1, I1.1, J9.2, J10.4, Q2.3 (D), U2.5 (TVDD), U2.8 (AVDD), U2.17 (I1), U2.39 (DVDD)
+BAT: +BAT1.1, BT1.1 (+), C17.2, D4.1, Q1.3 (D), R11.1, U2.40 (VBAT), U4.3 (BAT)
/M_SCL: J8.1, J8.2, U3.11 (PB0)
/M_SDA: J1.17, J1.18, U3.10 (PB1)
/OSCIN: C12.1, U2.14 (OSCIN), Y2.1
/OSCOUT: C13.1, U2.15 (OSCOUT), Y2.3
/PA0: D1.2 (A), J8.11, J8.12, SW2.3 (C), U3.16 (~RESET/PA0)
/PA1: J8.13, J8.14, PA1/MOSI/SDA/HSU_TX1.1, U2.28 (MOSI/SDA/HSU_TX), U3.17 (PA1)
/PA2: J8.15, J8.16, PA2/MISO/P71.1, U2.29 (MISO_/_P71), U3.18 (PA2)
/PA3: J8.17, J8.18, PA3/SCK/P72.1, U2.30 (SCK/P72), U3.19 (PA3)
/PA4: J1.1, J1.2, PA4/NSS/SCL/HSU_RX1.1, U2.27 (NSS/P50_SCL/HSU_RX), U3.2 (PA4)
/PA5: J1.3, J1.4, PA5/RSTPD_N1.1, U2.38 (RSTPD_N), U3.3 (PA5)
/PA6: J1.5, J1.6, U3.4 (PA6)
/PA7: J1.7, J1.8, PA7/IRQ1.1, U2.25 (P70_IRQ), U3.5 (PA7)
/PB2: J1.15, J1.16, SW2.1 (A), U3.9 (PB2)
/PB3: J1.13, J1.14, SW2.4 (A), U3.8 (PB3)
/PB4: J1.11, J1.12, U3.7 (PB4)
/PB5: J1.9, J1.10, U3.6 (PB5)
/PC0: J8.3, J8.4, U3.12 (PC0)
/PC1: J8.5, J8.6, PC1.1, R6.2, U3.13 (PC1)
/PC2: J8.7, J8.8, PC2.1, R7.2, U3.14 (PC2)
/PC3: J8.9, J8.10, PC3.1, R8.2, U3.15 (PC3)
/RX: C11.2, R2.2, RX1.1, U2.10 (RX)
/TX1: L1.2, TX1.1, U2.4 (TX1)
/TX2: L2.2, TX2.1, U2.6 (TX2)
/VMID: C10.1, R2.1, U2.9 (VMID)
/VOR: D4.3, J9.1
/V_REG: C22.1, J9.3, U1.2 (VO)
/V_USB: D4.2, J12.4, R4.2, U4.4 (V_{CC})
GND: BT1.2 (-), C7.2, C8.2, C9.2, C10.2, C12.2, C13.2, C14.2, C15.2, C16.2, C17.1, C18.2, C19.2, C20.2, C21.2, C22.2, C23.1, D5.2 (A), GND1.1, J10.2, J10.3, J10.5, J10.6, J12.6, Q1.2 (S), Q2.2 (S), R5.1, R9.1, R10.1, U1.1 (GND), U2.1 (DVSS), U2.3 (TVSS1), U2.7 (TVSS2), U2.11 (AVSS), U2.18 (TESTEN), U2.41, U3.20 (GND), U4.2 (GND), U6.6 (GND), Y2.2, Y2.4
unnamed: C3.2, C5.1, L1.1
unnamed: C4.2, C6.2, L2.1, R1.1
unnamed: C11.1, R1.2
unnamed: D1.1 (K), R3.2
unnamed: D2.2 (A), D3.2 (A), R4.1
unnamed: D2.1 (K), U4.1 (~CHRG)
unnamed: D3.1 (K), U4.5 (STDBY)
unnamed: D5.4 (B), R6.1
unnamed: D5.3 (G), R7.1
unnamed: D5.1 (R), R8.1
unnamed: C1.1, C1.2, C2.1, C2.2, C3.1, C4.1, C5.2, C6.1, J4.1, J4.2, J4.3
unnamed: J12.2, SW2.2 (B)
unnamed: J12.3, SW2.5 (B)
unnamed: Q1.1 (G), U6.1 (OD)
unnamed: Q2.1 (G), U6.3 (OC)
unnamed: R3.1, SW2.6 (C)
unnamed: I0.1, R10.2, U2.16 (I0)
unnamed: R5.2, U4.6 (PROG)
unnamed: R9.2, U6.2 (CS)
unnamed: C23.2, R11.2, U6.5 (VCC)
VCC: C16.1, C18.1, C19.1, C21.1, J10.1, U1.3 (VI), U2.23 (PVDD), U3.1 (VCC)

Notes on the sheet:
OSCILLATOR See User Manual 8.5.2
RF SECTION: See AN1445 Antenna Design Guide EMC Filter: TX1-TX2, L1, L2, C5, C6 Reduces harmonics and performs impedance transformation Matching Circuit: C1, C2, C3, C4 Acts as an impedance transformation block
Battery + Overcharge/Undercharge Controller
Decoupling (DVDD, AVDD, TVDD) DVDD and TVDD made based on PN532_C1 s13
Voltage OR Use whatever the highest voltage is
Power Management
Charger - 3.9k ohms = 256~ mA charging speed
I/O
RF Module (PN532)
Serial/FTDI Header
VRM (kind of not nessacary)
Power Inputs
Mounting Holes
Indicators (Not ODC, unfortunately)

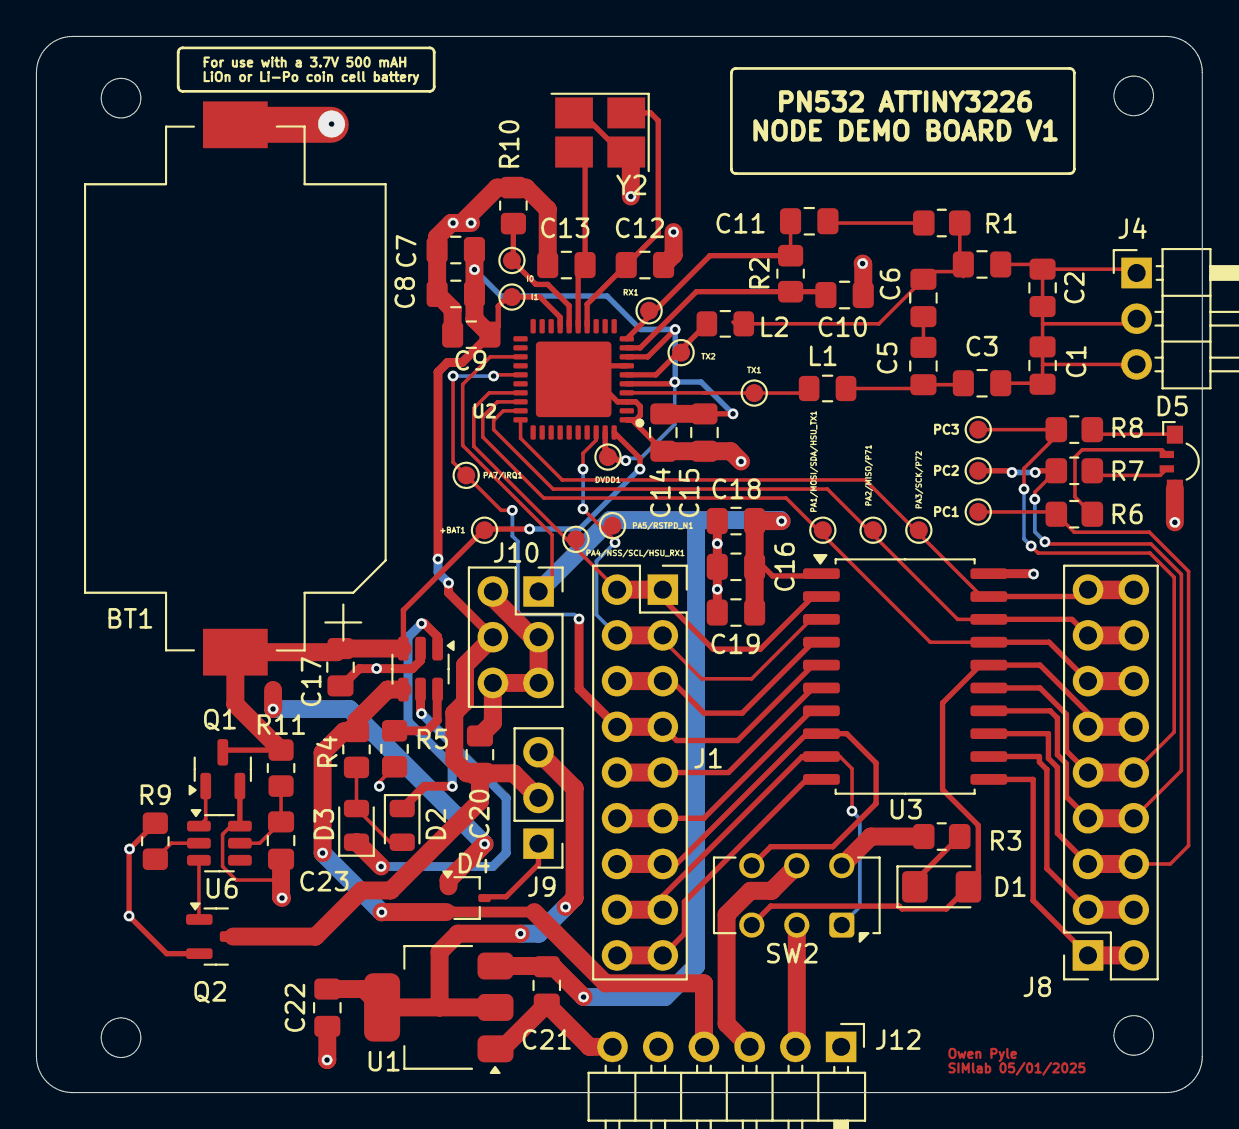
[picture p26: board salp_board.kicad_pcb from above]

Board: 4 copper layers, 64.8 x 58.7 mm, 77 parts (0 on the bottom side), 51 nets.

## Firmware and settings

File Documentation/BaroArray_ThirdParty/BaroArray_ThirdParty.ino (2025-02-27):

/* Blue Robotics MS5837 Library Example
-----------------------------------------------------

Title: Blue Robotics MS5837 Library Example

Description: This example demonstrates the MS5837 Library with a connected
sensor. The example reads the sensor and prints the resulting values
to the serial terminal.

The code is designed for the Arduino Uno board and can be compiled and
uploaded via the Arduino 1.0+ software.

-------------------------------
The MIT License (MIT)

Copyright (c) 2015 Blue Robotics Inc.

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
THE SOFTWARE IS PROVIDED "AS IS", WITHOUT WARRANTY OF ANY KIND, EXPRESS OR
IMPLIED, INCLUDING BUT NOT LIMITED TO THE WARRANTIES OF MERCHANTABILITY,
FITNESS FOR A PARTICULAR PURPOSE AND NONINFRINGEMENT. IN NO EVENT SHALL THE
AUTHORS OR COPYRIGHT HOLDERS BE LIABLE FOR ANY CLAIM, DAMAGES OR OTHER
LIABILITY, WHETHER IN AN ACTION OF CONTRACT, TORT OR OTHERWISE, ARISING FROM,
OUT OF OR IN CONNECTION WITH THE SOFTWARE OR THE USE OR OTHER DEALINGS IN
THE SOFTWARE.
-------------------------------*/

#include <Wire.h>
#include "MS5837.h"
#include "TCA9548A.h"
#include <SoftwareSerial.h>

MS5837 sensor0;
MS5837 sensor1;
MS5837 sensor2;
MS5837 sensor3;
MS5837 sensor4;
MS5837 sensor5;
MS5837 sensor6;
MS5837 sensor7;

MS5837 sensor_arr[8] = {sensor0, sensor1, sensor2, sensor3, sensor4, sensor5, sensor6, sensor7};
int pressures[8] = {};

TCA9548A I2CMux;

void setup() {

  I2CMux.begin(Wire);             // Wire instance is passed to the library
  I2CMux.closeAll();  

  Serial.begin(9600);

  Serial.println("Starting");

  Wire.begin();

  for(int i = 0; i < 8; i++){
    I2CMux.openChannel(i);

    // Initialize pressure sensor
    // Returns true if initialization was successful
    // We can't continue with the rest of the program unless we can initialize the sensor
    while (!sensor_arr[i].init()) {
      Serial.println("Init failed!");
      Serial.println("Are SDA/SCL connected correctly?");
      Serial.println("\n\n\n");
      delay(1000);
    }

    // .init sets the sensor model for us but we can override it if required.
    // Uncomment the next line to force the sensor model to the MS5837_30BA.
    sensor_arr[i].setModel(MS5837::MS5837_30BA);
    sensor_arr[i].setFluidDensity(997); // kg/m^3 (freshwater, 1029 for seawater)
    I2CMux.closeChannel(i);
  }
  
}

void loop() {
  // Update pressure and temperature readings
  
  Serial.println("Pressures (mbar): ");

  for(int i = 0; i < 8; i++){
    I2CMux.openChannel(i);
    sensor_arr[i].read();

    pressures[i] = sensor_arr[i].pressure();

    //Serial.print(sensor_arr[i].pressure());
    //Serial.print(" ");

    I2CMux.closeChannel(i);

    delay(150);
  }

  for(int i = 0; i < 8; i++){
    if(pressures[i] > 0){
      Serial.print(pressures[i]);
      Serial.print(" ");
    }
  }

  Serial.println(" ");
  
  /*Serial.print("Temperature: ");
  Serial.print(sensor.temperature());
  Serial.println(" deg C");

  Serial.print("Depth: ");
  Serial.print(sensor.depth());
  Serial.println(" m");

  Serial.print("Altitude: ");
  Serial.print(sensor.altitude());
  Serial.println(" m above mean sea level");*/

  delay(500);
}

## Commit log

2025-02-27 Documentation added
    Added documentation for the BMI270, PN532 module, current board schematics (still a WIP), ATTiny3226
    [BMI270_BOS.step, nfc_breakout.kicad_pcb, nfc_breakout.kicad_sch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]
2025-02-27 file pathing
    fixed some pathing, added a custom folder for my very "creative" board that's still a WIP
    [salp_board.kicad_pcb, salp_board.kicad_sch, untitled.kicad_sch]
2025-02-27 Ripped basic commands from elechouse driver, basic comments started
    Added some pretty basic comments from the usual manual on IF construction. A lot to go. It is 3:00 AM and I am taking a break.
2025-03-23 Significant Overhaul
    - was a bit too much work to write my own libraries, so implemented a few for now (with licenses) for now. will have to be optimized since the current memory usage is insanely high [3031/3072, 98.7% RAM] and [17597/32768, 53.7% Flash]
    [PN532.sch.kicad_sch, PN532_Mount.stl, PN532_T3226_Module.kicad_sch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]
2025-03-25 Started reciever code
    Most of the receiver code needs to be written first before this can be tested fully. Adding IMU data on too as "debug values". After optimizations, uses about 30% RAM and 40% flash.
2025-04-11 Added some stuff to the PN532
    - buffer reading and checking (need to change)
    [BMI270_BOS.step, salp_board.kicad_sch]
2025-04-23 Started PCB Layout
    [PN532.sch.kicad_sch, PN532_T3226_Module.kicad_sch, dvdd_pn532_sch.kicad_sch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]
2025-04-23 Added some stuff
    [PN532.sch.kicad_sch, PN532_T3226_Module.kicad_sch, dvdd_pn532_sch.kicad_sch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]
2025-04-25 Layout 1: No ERC/DRC done yet
    [salp_board.kicad_pcb]
2025-04-29 Semi-finalized PCB design
    [salp_board.kicad_pcb, salp_board.kicad_sch]
2025-05-04 Board V1 - sent to fab (?)
    [salp_board-B_Mask.gbr, salp_board-B_Paste.gbr, salp_board-B_Silkscreen.gbr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]
2025-05-16 Obtained pictures for SPS
    [salp_board.step]
